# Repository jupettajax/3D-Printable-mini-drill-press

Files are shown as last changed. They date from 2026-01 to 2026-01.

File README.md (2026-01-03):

This is a precision drill press designed for mainly PCB drilling, it can be also used for other materials. Most parts can be 3D printed or purchased from regular hardware stores.

Electronic side consists of custom made microcontroller-controlled interface, that handles PID-tuning of the motor speed to maintain a stable drilling speed as well as setting desired drilling speeds.
BLDC-motor, -controller and the 7-segment display can be bought ready-made from Aliexpress, Links will be updated later.

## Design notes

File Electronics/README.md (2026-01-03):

Printable STL files, designed in Siemens NX

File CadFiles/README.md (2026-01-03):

3D printable stl files and other files coming soon

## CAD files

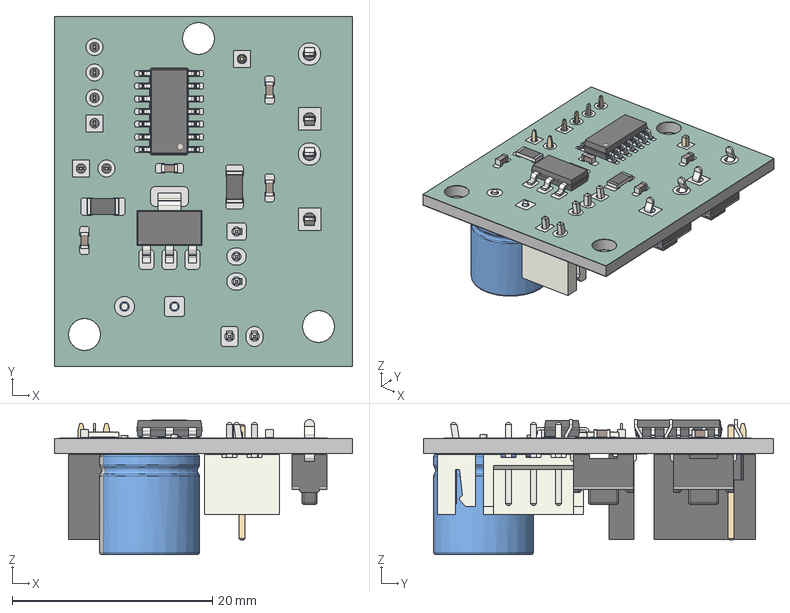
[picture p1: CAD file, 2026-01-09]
Electronics/Pylväspora.step
29.8 x 35.0 x 13.5 mm
SOT-223
R_1206_3216Metric x 2
C_0603_1608Metric x 4
SOIC-14_3.9x8.7mm_P1.27mm
SW_PUSH_1P1T_6x3.5mm_H5.0_APEM_MJTP1250 x 2
PinSocket_1x04_P2.54mm_Vertical
PinHeader_1x01_P2.54mm_Vertical
CP_Radial_D10.0mm_P5.00mm
JST_EH_B2B-EH-A_1x02_P2.50mm_Vertical
JST_EH_B3B-EH-A_1x03_P2.50mm_Vertical
PinSocket_1x02_P2.54mm_Vertical
PylvÃ¤spora_copper
PylvÃ¤spora_pad
PylvÃ¤spora_soldermask x 2
PylvÃ¤spora_PCB

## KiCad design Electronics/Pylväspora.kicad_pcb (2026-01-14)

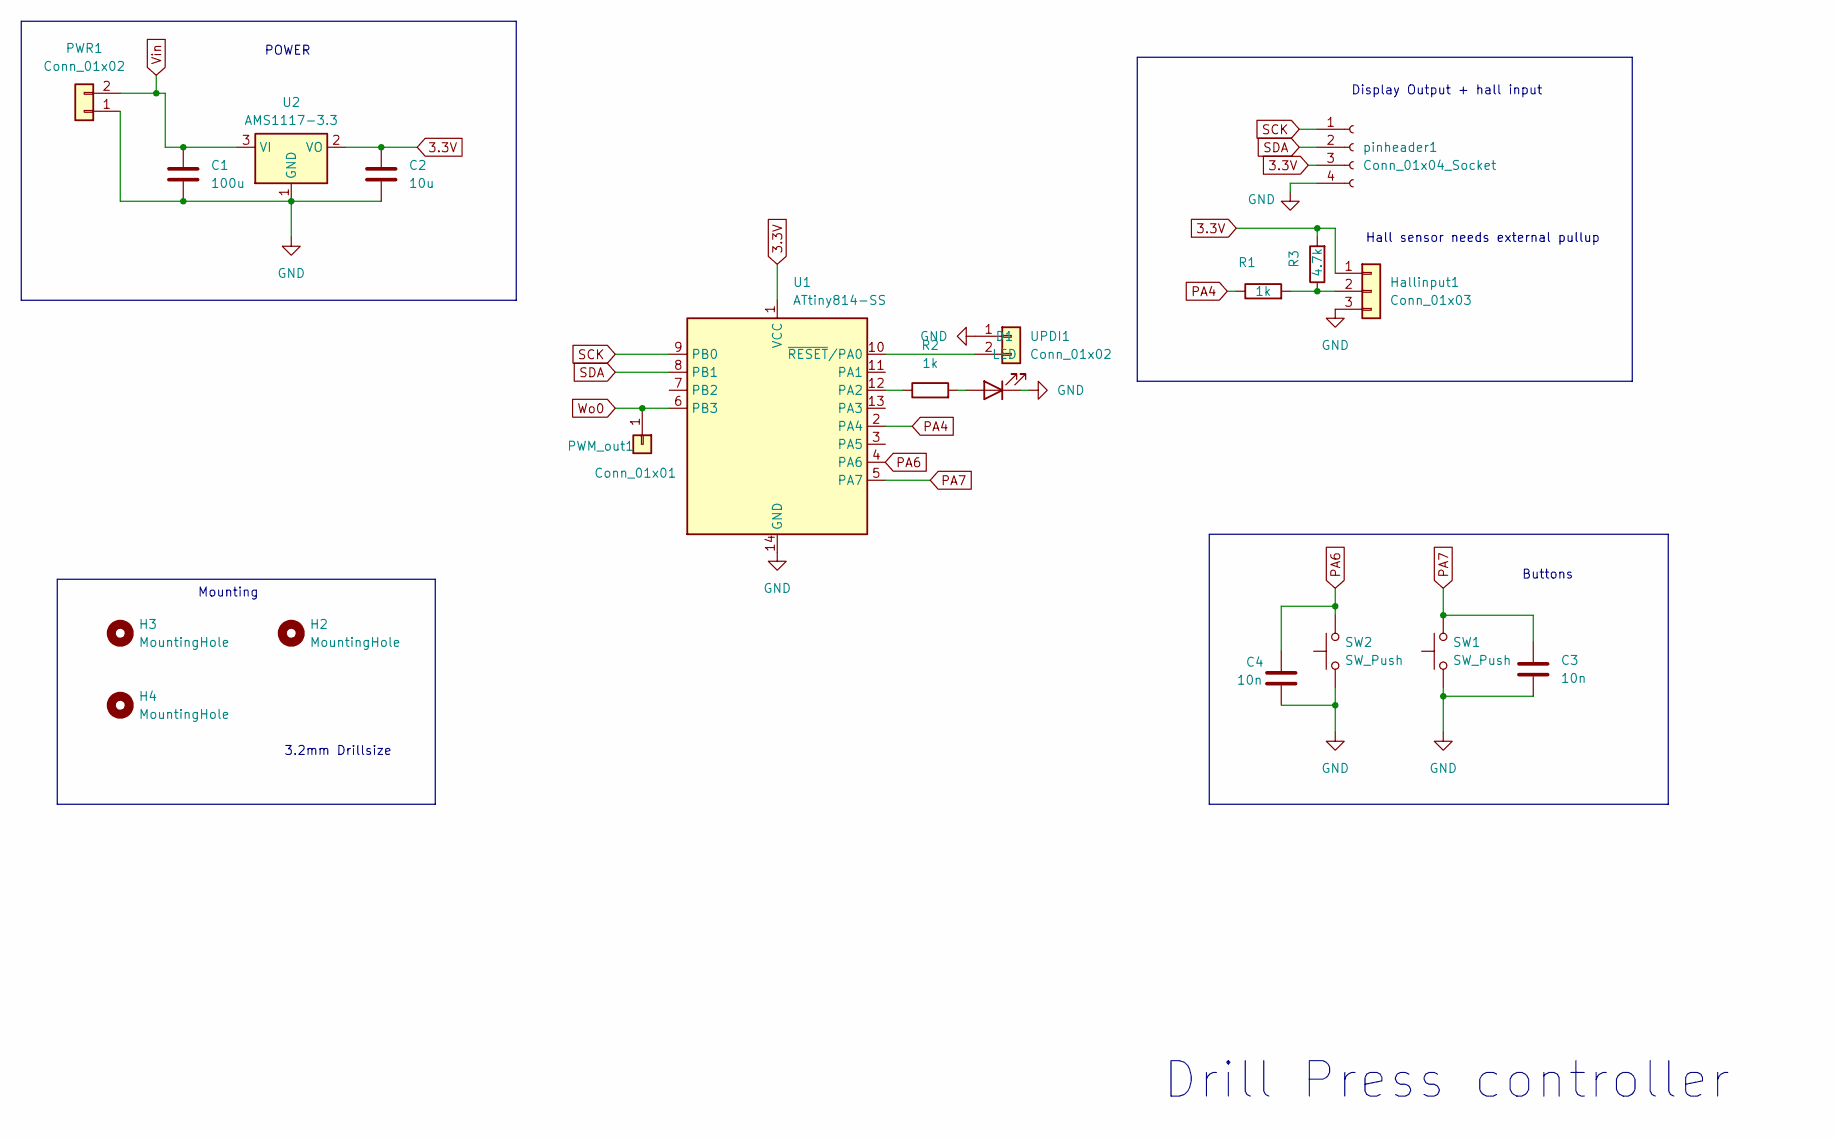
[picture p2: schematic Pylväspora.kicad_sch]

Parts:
C1: 100u; CP_Radial_D10.0mm_P5.00mm
C2: 10u; C_0603_1608Metric_Pad1.08x0.95mm_HandSolder
C3, C4: 10n; C_0603_1608Metric_Pad1.08x0.95mm_HandSolder
D1: LED; C_0603_1608Metric_Pad1.08x0.95mm_HandSolder
H2, H3, H4: MountingHole; MountingHole_3.2mm_M3
Hallinput1: Conn_01x03; JST_EH_B3B-EH-A_1x03_P2.50mm_Vertical
PWM_out1: Conn_01x01; PinHeader_1x01_P2.54mm_Vertical
PWR1: Conn_01x02; JST_EH_B2B-EH-A_1x02_P2.50mm_Vertical
R1, R2: 1k; R_1206_3216Metric_Pad1.30x1.75mm_HandSolder
R3: 4.7k; R_1206_3216Metric_Pad1.30x1.75mm_HandSolder
SW1, SW2: SW_Push; SW_PUSH_1P1T_6x3.5mm_H5.0_APEM_MJTP1250
U1: ATtiny814-SS; SOIC-14_3.9x8.7mm_P1.27mm
U2: AMS1117-3.3; SOT-223-3_TabPin2
UPDI1: Conn_01x02; PinSocket_1x02_P2.54mm_Vertical
pinheader1: Conn_01x04_Socket; PinSocket_1x04_P2.54mm_Vertical

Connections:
3.3V: C2.1, Hallinput1.1, R3.2, U1.1 (VCC), U2.2 (VO), pinheader1.3
GND: C1.2, C2.2, C3.2, C4.2, D1.1 (K), Hallinput1.3, PWR1.1, SW1.1, SW2.1, U1.14 (GND), U2.1 (GND), UPDI1.1, pinheader1.4
unnamed: D1.2 (A), R2.2
unnamed: Hallinput1.2, R1.2, R3.1
unnamed: R2.1, U1.12 (PA2)
unnamed: U1.10 (~RESET/PA0), UPDI1.2
PA4: R1.1, U1.2 (PA4)
PA6: C4.1, SW2.2, U1.4 (PA6)
PA7: C3.1, SW1.2, U1.5 (PA7)
SCK: U1.9 (PB0), pinheader1.1
SDA: U1.8 (PB1), pinheader1.2
Vin: C1.1, PWR1.2, U2.3 (VI)
Wo0: PWM_out1.1, U1.6 (PB3)

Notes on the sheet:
Mounting
Drill Press controller
Hall sensor needs external pullup
Buttons
POWER
3.2mm Drillsize
Display Output + hall input

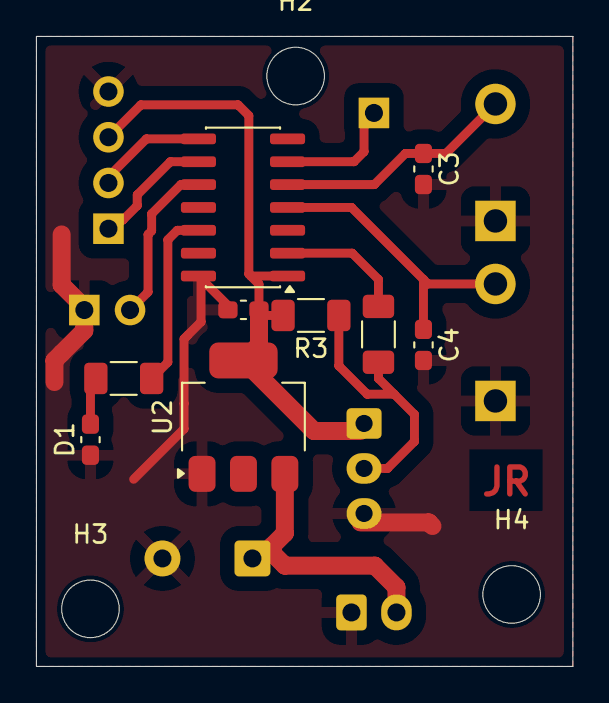
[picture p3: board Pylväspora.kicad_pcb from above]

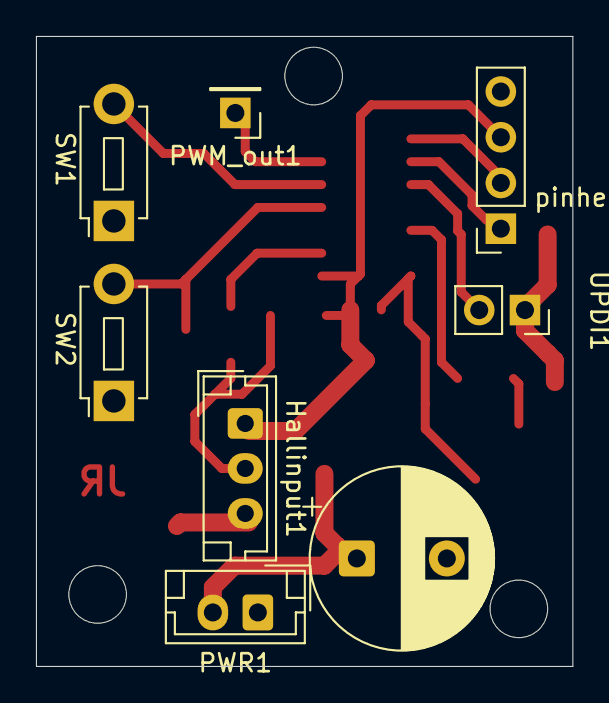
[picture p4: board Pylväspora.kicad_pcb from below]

Board: 2 copper layers, 29.8 x 35.0 mm, 20 parts (8 on the bottom side), 13 nets.

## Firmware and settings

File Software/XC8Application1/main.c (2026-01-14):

/*
 * main.c
 *
 * Created: 1/9/2026 1:37:51 PM
 *  Author: Justus
 */ 
#define F_CPU 10000000UL// 10 MHZ clock
#include <xc.h>
#include <util/delay.h>
#include <avr/interrupt.h>



#define Button1 PIN7_bm  // PORTA
#define Button2 PIN6_bm  // PORTA
#define LedPin PIN2_bm   // PORTA
#define PWM PIN3_bm		 // PORTB
#define Hall PIN4_bm	 // PORTA 

// Display

#define  CLK PIN0_bm // PORTB
#define DIO PIN1_bm // PORTB

volatile int8_t speedMode = 0; 
int8_t lastMode = 0;
uint8_t buttonflag = 0;
volatile uint16_t Pulses = 0;
uint16_t RPM = 0; 
uint8_t skiptime = 0; // Per 100ms

const uint8_t digitMap[10] = {
	0x3F, // 0
	0x06, // 1
	0x5B, // 2
	0x4F, // 3
	0x66, // 4
	0x6D, // 5
	0x7D, // 6
	0x07, // 7
	0x7F, // 8
	0x6F  // 9
};

void TM_sendByte(uint8_t data){
	for(int i = 0; i<8; i++){
		
		PORTB.OUTCLR = CLK;
		
		if (data & (1<<i)) // if value at index (lsb first)
		{
			PORTB.OUTSET = DIO;
		}
		else {
			PORTB.OUTCLR = DIO;
		}
		
		PORTB.OUTSET = CLK;
	}
	
	// WAIT FOR ACK
	PORTB.OUTCLR = CLK;
	PORTB.DIRCLR = DIO; // To input
	PORTB.OUTSET = CLK;
	_delay_ms(1);
	PORTB.OUTCLR = CLK;
	PORTB.DIRSET = DIO; // Back to Output
}

void TM_start(void){
	PORTB.OUTSET = CLK | DIO;
	PORTB.OUTCLR = DIO;
	PORTB.OUTCLR = CLK;
}

void TM_stop(void){
	PORTB.OUTCLR = CLK;
	PORTB.OUTCLR = DIO;
	PORTB.OUTSET = CLK;
	PORTB.OUTSET = DIO;
}
void TM_displayInit(void){
	TM_start();
	TM_sendByte(0x40);  // auto increment
	TM_stop();

	TM_start();
	TM_sendByte(0x88 | 0x07); // display ON, max brightness
	TM_stop();
}

void TM_printNumber(uint16_t num)
{
	uint8_t digits[4];

	if (num > 9999) num = 9999;

	digits[0] = digitMap[(num / 1000) % 10];
	digits[1] = digitMap[(num / 100)  % 10];
	digits[2] = digitMap[(num / 10)   % 10];
	digits[3] = digitMap[num % 10];

	TM_start();
	TM_sendByte(0xC0);      // Start form 0
	for (uint8_t i = 0; i < 4; i++)
	TM_sendByte(digits[i]);
	TM_stop();
	
}

void setSpeed(uint16_t us){
	TCA0.SINGLE.CMP0 = (uint32_t)us * 625 / 1000;
}

void setup(void){
	// Setup cpu clockspeed
	CPU_CCP = CCP_IOREG_gc; // Write protection off
	CLKCTRL.MCLKCTRLB = CLKCTRL_PEN_bm | CLKCTRL_PDIV_2X_gc; // 20 MHz clk, 2x Prescale = 10 MHZ

	
	// Buttons to input
	PORTA.DIRCLR = Button1;
	PORTA.DIRCLR = Button2;
	// Button internal pull-ups
	PORTA.PIN7CTRL = PORT_PULLUPEN_bm;
	PORTA.PIN6CTRL = PORT_PULLUPEN_bm;
	// Button interrupts
	PORTA.PIN7CTRL |= PORT_ISC_FALLING_gc;
	PORTA.PIN6CTRL |= PORT_ISC_FALLING_gc;
	// On board led output
	PORTA.DIRSET = LedPin;
	// Hall input from motor sensor
	PORTA.DIRCLR = Hall; // Hall pin to output
	PORTA.PIN4CTRL = PORT_ISC_FALLING_gc;
	// TM 1637 display
	PORTB.DIRSET = CLK; // Both to output
	PORTB.DIRSET = DIO;
	PORTB.OUTSET = CLK; // Both high
	PORTB.OUTSET = DIO;
	// Configure PWM output for ESC
	PORTB.DIRSET = PWM; // PWM pin to output
	PORTMUX_CTRLC = PORTMUX_TCA00_ALTERNATE_gc; // WO0 to alternate pin (PB3)

	TCA0.SINGLE.CTRLB = TCA_SINGLE_WGMODE_SINGLESLOPE_gc | TCA_SINGLE_CMP0EN_bm;
	TCA0.SINGLE.PER = 12500;
	TCA0.SINGLE.CMP0 = 625;
	TCA0.SINGLE.CTRLA = TCA_SINGLE_ENABLE_bm | TCA_SINGLE_CLKSEL_DIV16_gc;
	
	TM_displayInit();
	sei();
	PORTA.OUTSET = LedPin; // Led on
}

ISR(PORTA_PORT_vect){
	if (PORTA.INTFLAGS & Hall)
	{
		Pulses++;
		PORTA.OUTTGL = LedPin;
	}
	else
	{
		buttonflag = 1;
	}
	PORTA.INTFLAGS = 0xff;
}

int main(void)
{
	setup();
	TM_printNumber(0000);
	_delay_ms(1000);
    while(1)
    {
		if(buttonflag){
			buttonflag = 0;
			uint8_t buttons = PORTA.IN;
			if(!(buttons & Button1)){
				speedMode++;
			}
			if(!(buttons & Button2)){
				speedMode--;
			}
			if (speedMode < 0){		 // Prevent mode from going negative
				speedMode = 0;
			}
		}
		
		if(lastMode != speedMode){			// Display mode for one second when changed
			lastMode = speedMode;
			skiptime = 0;
		}
		
		if (skiptime < 10)
		{
			TM_printNumber(speedMode);
			skiptime++;
		}
		else{
		
			TM_printNumber(RPM);
		}
		
		setSpeed(1000+speedMode*100);
		
		RPM = (uint16_t) Pulses / 0.06 * 60; // 6 pairs of magnets 
		Pulses = 0;
		
		_delay_ms(10);
		
    }
} 

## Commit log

2026-01-03 Added KiCad Files
    [Pylväspora.kicad_pcb, Pylväspora.kicad_sch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]
2026-01-03 Fixed location of KiCad files
    [Pylväspora.kicad_pcb, Pylväspora.kicad_sch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]
2026-01-03 Corrected jst model footprints
    [Pylväspora.kicad_pcb, Pylväspora.kicad_sch]
2026-01-09 Software ios, display driving logic, buttons
    Software ios, display driving logic, buttons
    [Pylväspora.kicad_sch, Pylväspora.step]
2026-01-13 Added Motor hall sensor input and rpm calculations,, fixed logic
    [main.c]
2026-01-14 Small schematic and layout fix
    Forgot a pullup resistor from hall input, added 4.7k pullup. Fixed incorrect measurement of RPM and increased update frequency in software
    [Pylväspora.kicad_pcb, Pylväspora.kicad_sch]
